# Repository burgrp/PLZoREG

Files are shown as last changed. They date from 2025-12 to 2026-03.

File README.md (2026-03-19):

# PLZoREG - PV Power Regulator

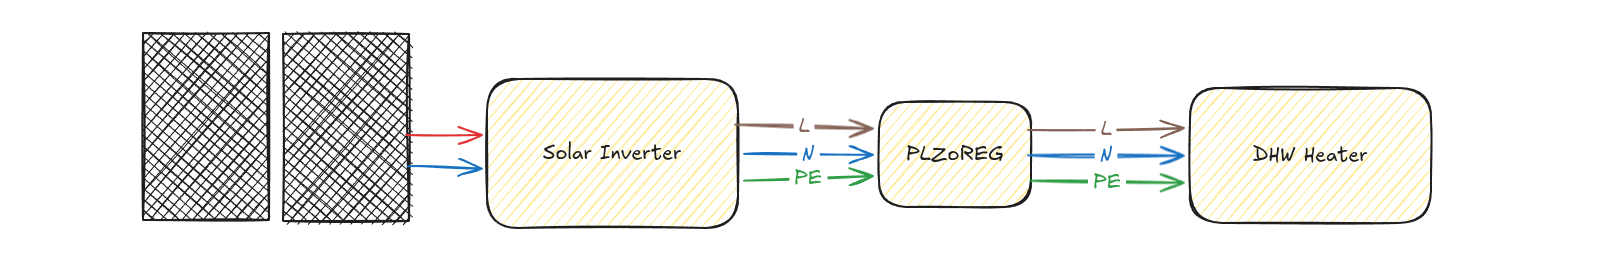
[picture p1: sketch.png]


PLZoREG is a power regulator designed to sit between a photovoltaic (PV) inverter and a domestic hot water (DHW) heater. It solves the problem of cheap grid-tie inverters oscillating under varying loads during cloudy conditions, which causes audible noise from the heating elements.

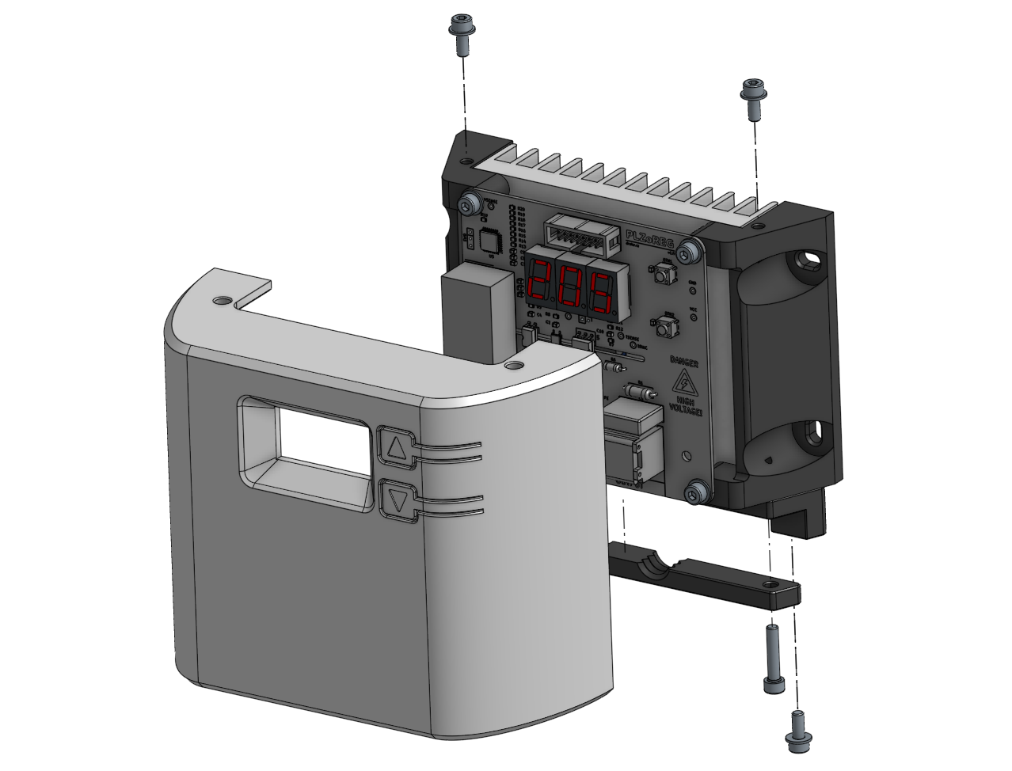
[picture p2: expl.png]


Designed in [Onshape](https://cad.onshape.com/documents/f103c5e3fbe2c6c85b2f1c34/w/b57b1089b11cbe9058b16474/e/0dcdb83c0b13157c67edb204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).

## Problem Statement

Low-cost PV inverters often struggle to maintain stable output when the load (DHW heater) exceeds the available solar power on cloudy days. The inverter attempts to deliver maximum power but fails to maintain output voltage, causing the load to cycle on and off rapidly. This creates:
- Audible buzzing/humming from heating spirals
- Inefficient operation and potential inverter shutdown
- Reduced energy harvesting

## Solution

PLZoREG monitors the inverter's output voltage and dynamically adjusts power delivery to the heater using phase-angle PWM control. By maintaining the inverter's output voltage above a configurable threshold, it prevents voltage collapse and keeps the inverter operating in its stable region.

### Key Features

- **Voltage monitoring**: Real-time measurement of inverter output voltage
- **Adaptive PWM regulation**: Automatic duty cycle adjustment (0-100%)
- **User-configurable target voltage**: Set target between 100-240V
- **Temperature monitoring**: Heater and MCU temperature sensing
- **Safety features**: Overtemperature protection, zero-cross synchronization detection
- **Persistent settings**: Target voltage stored in flash memory
- **Simple 2-button interface**: 3-digit 7-segment display with up/down controls

## Hardware

The hardware design is located in `board/` (KiCad 8 project).

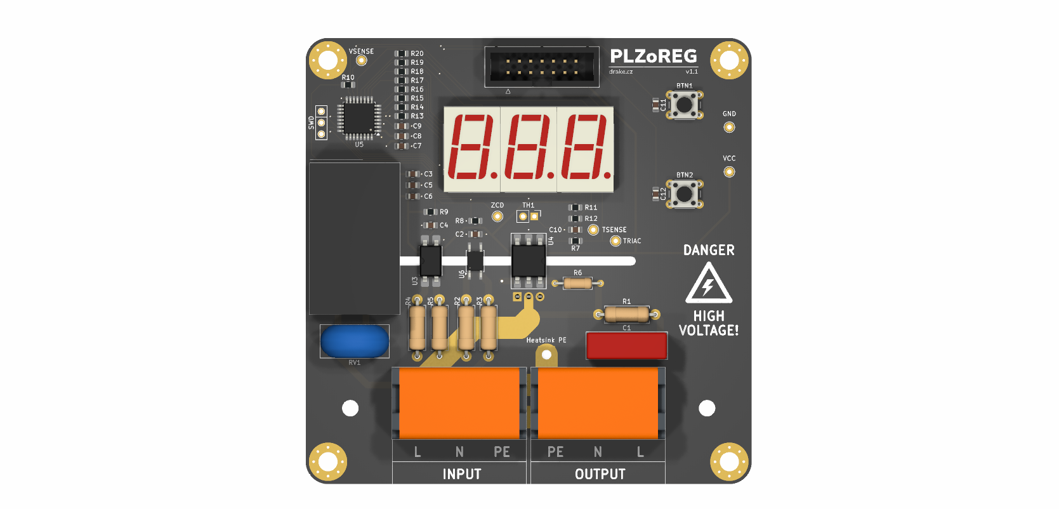
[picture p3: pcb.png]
PCB


**Microcontroller**: PY32F030x8 (ARM Cortex-M0+)

**Key Components**:
- Zero-cross detection for AC synchronization
- Phase-angle PWM control for power regulation
- Voltage sensing circuitry
- Temperature sensors (NTC for heater, internal for MCU)
- 3-digit 7-segment LED display
- 2-button user interface

## Firmware

The firmware is written in TinyGo and located in `fw/`.

### Prerequisites

- [TinyGo](https://tinygo.org/) (latest version recommended)
- [pyOCD](https://pyocd.io/) for flashing
- ARM GCC toolchain (for debugging)
- Make

### Building and Flashing

```bash
cd fw
make build    # Compile firmware
make flash    # Build and flash to device
```

### Debugging

```bash
make gdb      # Start GDB server with semihosting
make rtt      # Connect to RTT output for debug messages
```

### Architecture

**Key Packages**:
- `main.go`: Main control loop, state machine, regulation algorithm
- `display/`: 7-segment LED display driver (hardware-abstracted with build tags)
- `keyboard/`: Button input handler with key repeat and press detection
- `flash/`: Flash memory operations for persistent settings
- `adc/`, `pwm/`, `zcd/`: Hardware peripheral drivers

**Control Algorithm**:
The regulation loop (500ms cycle) compares sensed voltage with target voltage:
- If `VSense < VTarget`: Decrease duty cycle (reduce load)
- If `VSense > VTarget`: Increase duty cycle (increase load)
- Duty cycle changes by ±1% per cycle for smooth regulation

**Build Tags**: The project uses Go build tags for hardware abstraction:
- `py32`: PY32 family-specific code
- `py32f030`: PY32F030 variant-specific pin mappings

### User Interface

The firmware provides a page-based UI with 5 information pages:
1. **Voltage Sense** (no decimal): Current inverter voltage (e.g., `220`)
2. **Voltage Target** (trailing decimal): Target voltage setpoint - adjustable (e.g., `220.`)
3. **Duty Cycle** (decimal format): Current PWM duty cycle (e.g., `0.75` = 75%)
4. **Triac Temperature** (° symbol): Triac heatsink temperature (e.g., `50°`)
5. **MCU Temperature** (.° symbols): Microcontroller temperature (e.g., `50.°`)

Navigation:
- **Up/Down buttons**: Cycle through pages
- **Hold both buttons (1s)**: Enter/exit setting mode on adjustable pages (V. and .d)
- **In setting mode**: Up/Down buttons adjust the value

Error Codes:
- **E01**: No zero-cross synchronization detected
- **E02**: Overtemperature (triac > 90°C)

## Development

See [CLAUDE.md](CLAUDE.md) for detailed development guidance and architecture notes for AI assistants.

### Code Style

- Minimal abstractions: code is direct and hardware-focused
- No dynamic memory allocation (GC disabled)
- Task-based scheduler
- Prefer clarity over brevity

### Making Changes

1. Ensure all builds run from `fw/` directory
2. Test display changes across build tag variants
3. Verify settings persistence after power cycle
4. Check regulation stability under varying voltage conditions

## License

[Add license information]

## Contributing

[Add contribution guidelines if applicable]

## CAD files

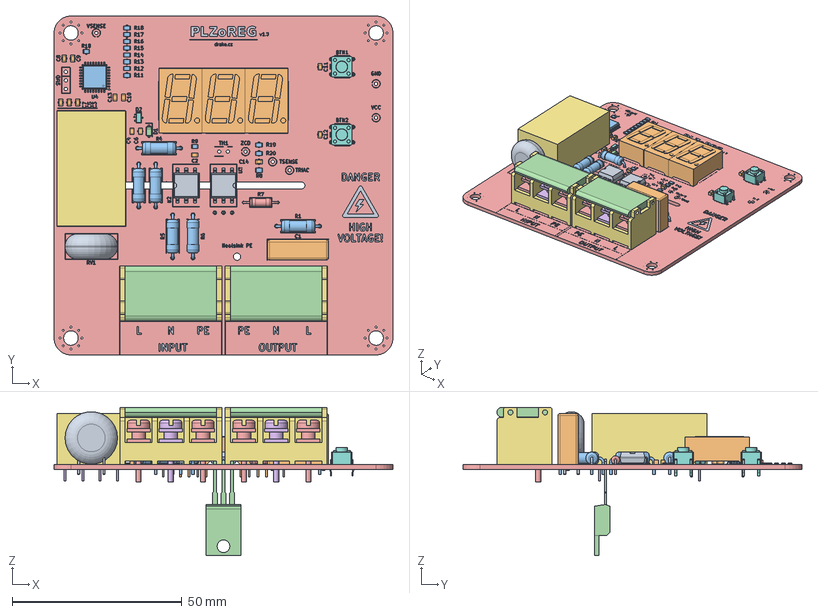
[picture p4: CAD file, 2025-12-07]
board/plzoreg.step
100.0 x 100.0 x 43.8 mm
C_0805_2012Metric x 13
R_0805_2012Metric x 13
cover x 2
contact 1 x 2
SOT-23
RV_Disc_D15.5mm_W7.5mm_P7.5mm
7SegmentLED_LTS6760_LTS6780 x 3
R_Axial_DIN0411_L9.9mm_D3.6mm_P12.70mm_Horizontal x 6
D_SOD-123
R_Axial_DIN0207_L6.3mm_D2.5mm_P10.16mm_Horizontal
HLK-PM01-ac2
HLK-PM01-vo-
HLK-PM01-vo+
HLK-PM01-ac1
HLK-PM01-body
SW_PUSH_6mm_H5mm x 2
DIP-6_W8.89mm_SMDSocket x 2
C_Rect_L18.0mm_W6.0mm_P15.00mm_FKS3_FKP3
LQFP-32_7x7mm_P0.8mm
TO-220-3_Vertical
plzoreg_silkscreen x 2
plzoreg_PCB

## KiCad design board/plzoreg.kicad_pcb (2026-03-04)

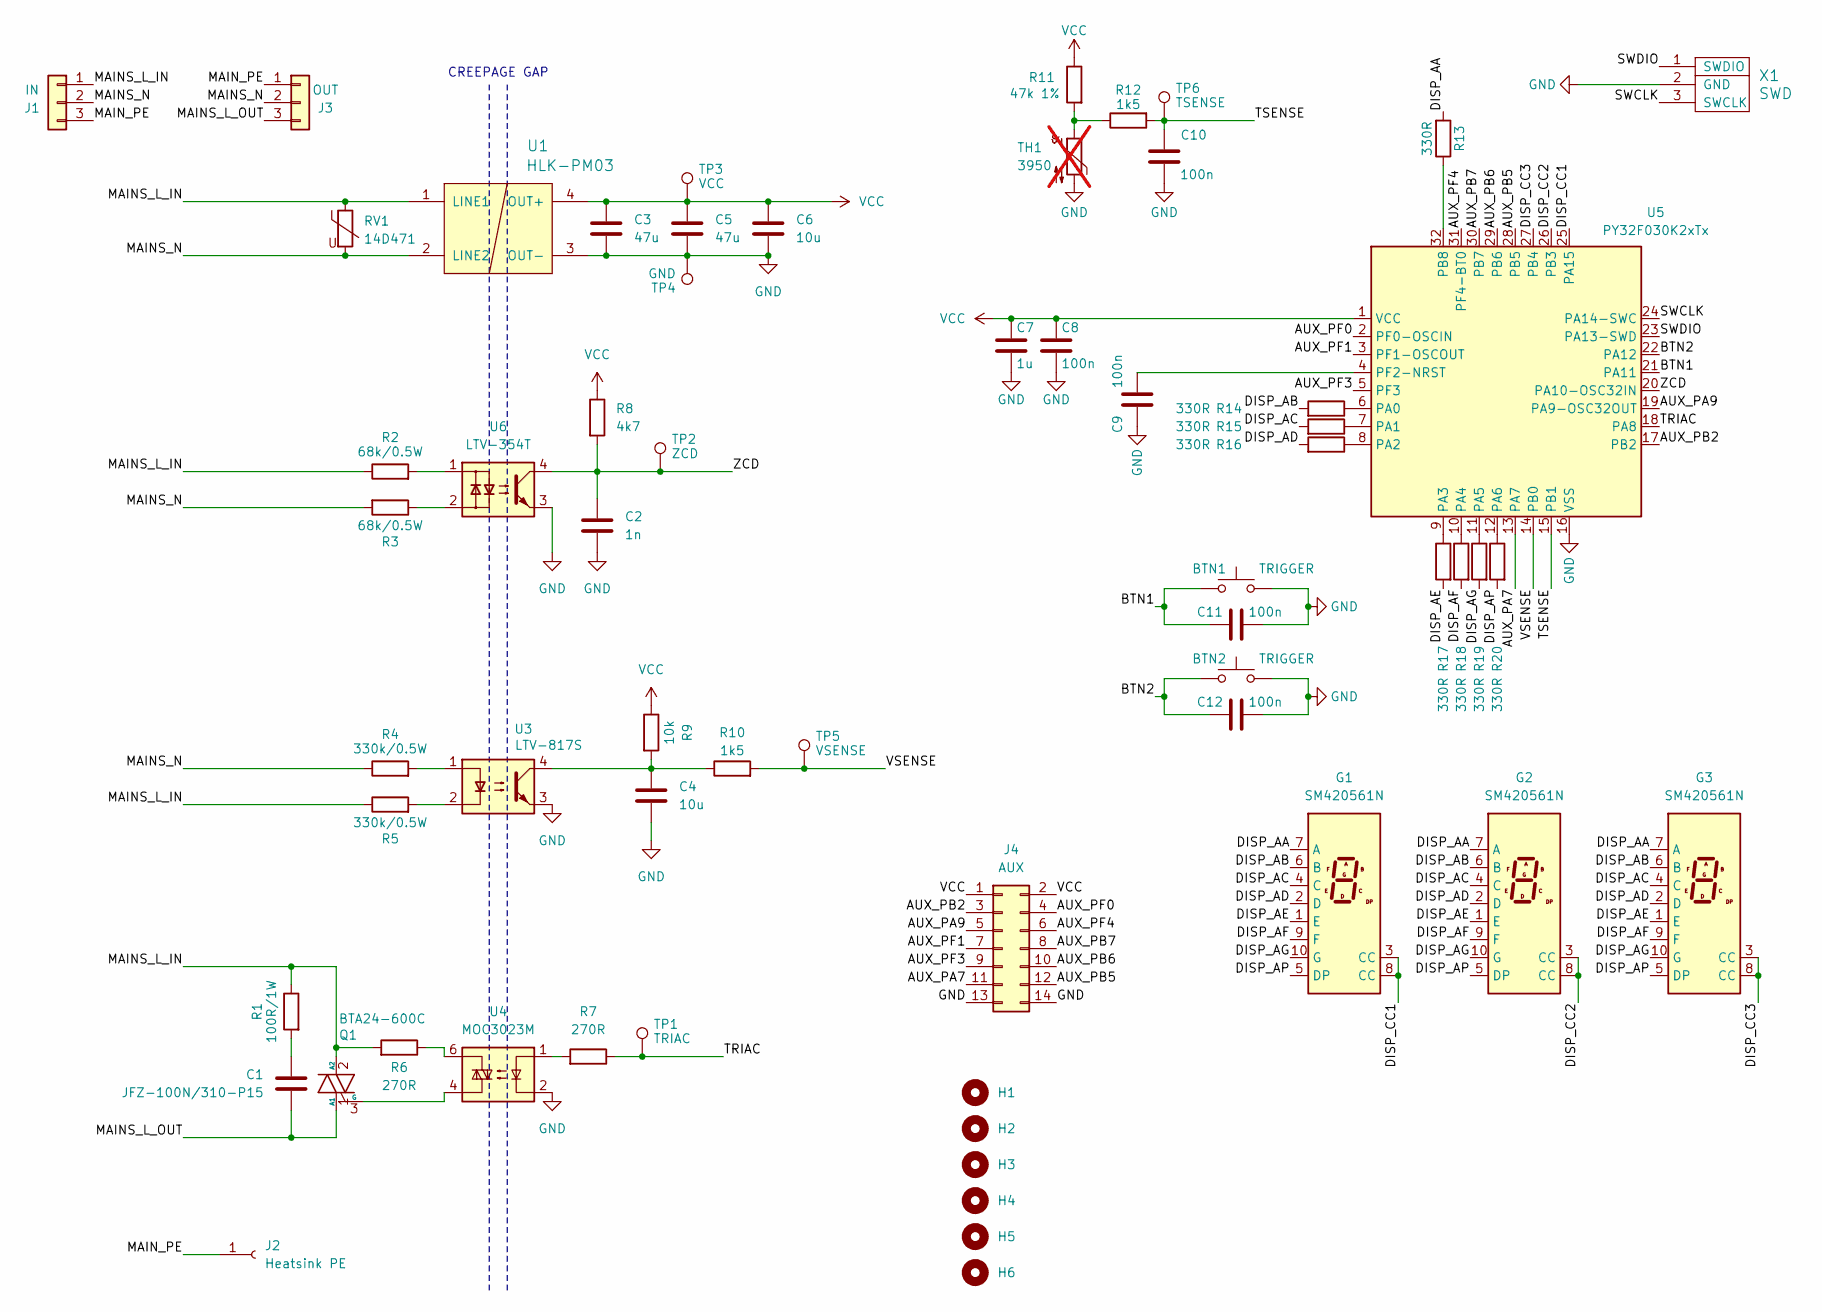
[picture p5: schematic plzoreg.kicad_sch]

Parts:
BTN1, BTN2: TRIGGER; SW_PUSH_6mm_H5mm
C1: JFZ-100N/310-P15; C_Rect_L18.0mm_W6.0mm_P15.00mm_FKS3_FKP3
C2: 1n; C_0805_2012Metric_Pad1.18x1.45mm_HandSolder
C3, C5: 47u; C_0805_2012Metric_Pad1.18x1.45mm_HandSolder
C4, C6: 10u; C_0805_2012Metric_Pad1.18x1.45mm_HandSolder
C7: 1u; C_0805_2012Metric_Pad1.18x1.45mm_HandSolder
C8, C9, C10, C11, C12: 100n; C_0805_2012Metric_Pad1.18x1.45mm_HandSolder
G1, G2, G3: SM420561N; 7SegmentLED_LTS6760_LTS6780
H1, H2, H3, H4: MountingHole; MountingHole_4.3mm_M4_Pad_Via
H5, H6: MountingHole; MountingHole_3.7mm
J1: IN; HB-9500-3P
J2: Heatsink PE; SolderWire-1.5sqmm_1x01_D1.7mm_OD3.9mm
J3: OUT; HB-9500-3P
J4: AUX; IDC-Header_2x07_P2.54mm_Vertical
Q1: BTA24-600C; TO-220-3_Vertical
R1: 100R/1W; R_Axial_DIN0411_L9.9mm_D3.6mm_P12.70mm_Horizontal
R2, R3: 68k/0.5W; R_Axial_DIN0411_L9.9mm_D3.6mm_P12.70mm_Horizontal
R4, R5: 330k/0.5W; R_Axial_DIN0411_L9.9mm_D3.6mm_P12.70mm_Horizontal
R6: 270R; R_Axial_DIN0207_L6.3mm_D2.5mm_P10.16mm_Horizontal
R7: 270R; R_0805_2012Metric_Pad1.20x1.40mm_HandSolder
R8: 4k7; R_0805_2012Metric_Pad1.20x1.40mm_HandSolder
R9: 10k; R_0805_2012Metric_Pad1.20x1.40mm_HandSolder
R10, R12: 1k5; R_0805_2012Metric_Pad1.20x1.40mm_HandSolder
R11: 47k 1%; R_0805_2012Metric_Pad1.20x1.40mm_HandSolder
R13, R14, R15, R16, R17, R18, R19, R20: 330R; R_0805_2012Metric_Pad1.20x1.40mm_HandSolder
RV1: 14D471; RV_Disc_D15.5mm_W7.5mm_P7.5mm
TH1: 3950; PinHeader_1x02_P2.54mm_Vertical; not fitted
TP1: TRIAC; TestPoint_THTPad_D2.0mm_Drill1.0mm
TP2: ZCD; TestPoint_THTPad_D2.0mm_Drill1.0mm
TP3: VCC; TestPoint_THTPad_D2.0mm_Drill1.0mm
TP4: GND; TestPoint_THTPad_D2.0mm_Drill1.0mm
TP5: VSENSE; TestPoint_THTPad_D2.0mm_Drill1.0mm
TP6: TSENSE; TestPoint_THTPad_D2.0mm_Drill1.0mm
U1: HLK-PM03; HLK-PM01
U3: LTV-817S; SMDIP-4_W9.53mm
U4: MOC3023M; DIP-6_W8.89mm_SMDSocket_LongPads
U5: PY32F030K2xTx; LQFP-32_7x7mm_P0.8mm
U6: LTV-354T; SO-4_4.4x3.6mm_P2.54mm
X1: SWD

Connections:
/AUX_PA7: J4.11, U5.13 (PA7)
/AUX_PA9: J4.5, U5.19 (PA9-OSC32OUT)
/AUX_PB2: J4.3, U5.17 (PB2)
/AUX_PB5: J4.12, U5.28 (PB5)
/AUX_PB6: J4.10, U5.29 (PB6)
/AUX_PB7: J4.8, U5.30 (PB7)
/AUX_PF0: J4.4, U5.2 (PF0-OSCIN)
/AUX_PF1: J4.7, U5.3 (PF1-OSCOUT)
/AUX_PF3: J4.9, U5.5 (PF3)
/AUX_PF4: J4.6, U5.31 (PF4-BT0)
/BTN1: BTN1.1, C11.1, U5.21 (PA11)
/BTN2: BTN2.1, C12.1, U5.22 (PA12)
/DISP_AA: G1.7 (A), G2.7 (A), G3.7 (A), R13.2
/DISP_AB: G1.6 (B), G2.6 (B), G3.6 (B), R14.2
/DISP_AC: G1.4 (C), G2.4 (C), G3.4 (C), R15.2
/DISP_AD: G1.2 (D), G2.2 (D), G3.2 (D), R16.2
/DISP_AE: G1.1 (E), G2.1 (E), G3.1 (E), R17.2
/DISP_AF: G1.9 (F), G2.9 (F), G3.9 (F), R18.2
/DISP_AG: G1.10 (G), G2.10 (G), G3.10 (G), R19.2
/DISP_AP: G1.5 (DP), G2.5 (DP), G3.5 (DP), R20.2
/DISP_CC1: G1.3 (CC), G1.8 (CC), U5.25 (PA15)
/DISP_CC2: G2.3 (CC), G2.8 (CC), U5.26 (PB3)
/DISP_CC3: G3.3 (CC), G3.8 (CC), U5.27 (PB4)
/MAINS_L_IN: J1.1, Q1.2 (A2), R1.1, R2.1, R5.1, R6.2, RV1.1, U1.1 (LINE1)
/MAINS_L_OUT: C1.2, J3.3, Q1.1 (A1)
/MAINS_N: J1.2, J3.2, R3.2, R4.1, RV1.2, U1.2 (LINE2)
/MAIN_PE: J1.3, J2.1, J3.1
/SWCLK: U5.24 (PA14-SWC), X1.3 (SWCLK)
/SWDIO: U5.23 (PA13-SWD), X1.1 (SWDIO)
/TRIAC: R7.1, TP1.1, U5.18 (PA8)
/TSENSE: C10.2, R12.2, TP6.1, U5.15 (PB1)
/VSENSE: R10.2, TP5.1, U5.14 (PB0)
/ZCD: C2.1, R8.2, TP2.1, U5.20 (PA10-OSC32IN), U6.4
GND: BTN1.2, BTN2.2, C2.2, C3.2, C4.2, C5.2, C6.2, C7.2, C8.2, C9.2, C10.1, C11.2, C12.2, J4.13, J4.14, TH1.2, TP4.1, U1.3 (OUT-), U3.3, U4.2, U5.16 (VSS), U6.3, X1.2 (GND)
unnamed: C1.1, R1.2
unnamed: C4.1, R9.2, R10.1, U3.4
unnamed: Q1.3 (G), U4.4
unnamed: R2.2, U6.1
unnamed: R3.1, U6.2
unnamed: R4.2, U3.1
unnamed: R5.2, U3.2
unnamed: R6.1, U4.6
unnamed: R7.2, U4.1
unnamed: R11.2, R12.1, TH1.1
unnamed: R14.1, U5.6 (PA0)
unnamed: R15.1, U5.7 (PA1)
unnamed: R16.1, U5.8 (PA2)
unnamed: R17.1, U5.9 (PA3)
unnamed: R18.1, U5.10 (PA4)
unnamed: R19.1, U5.11 (PA5)
unnamed: R20.1, U5.12 (PA6)
unnamed: R13.1, U5.32 (PB8)
unnamed: C9.1, U5.4 (PF2-NRST)
VCC: C3.1, C5.1, C6.1, C7.1, C8.1, J4.1, J4.2, R8.1, R9.1, R11.1, TP3.1, U1.4 (OUT+), U5.1 (VCC)

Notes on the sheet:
CREEPAGE GAP

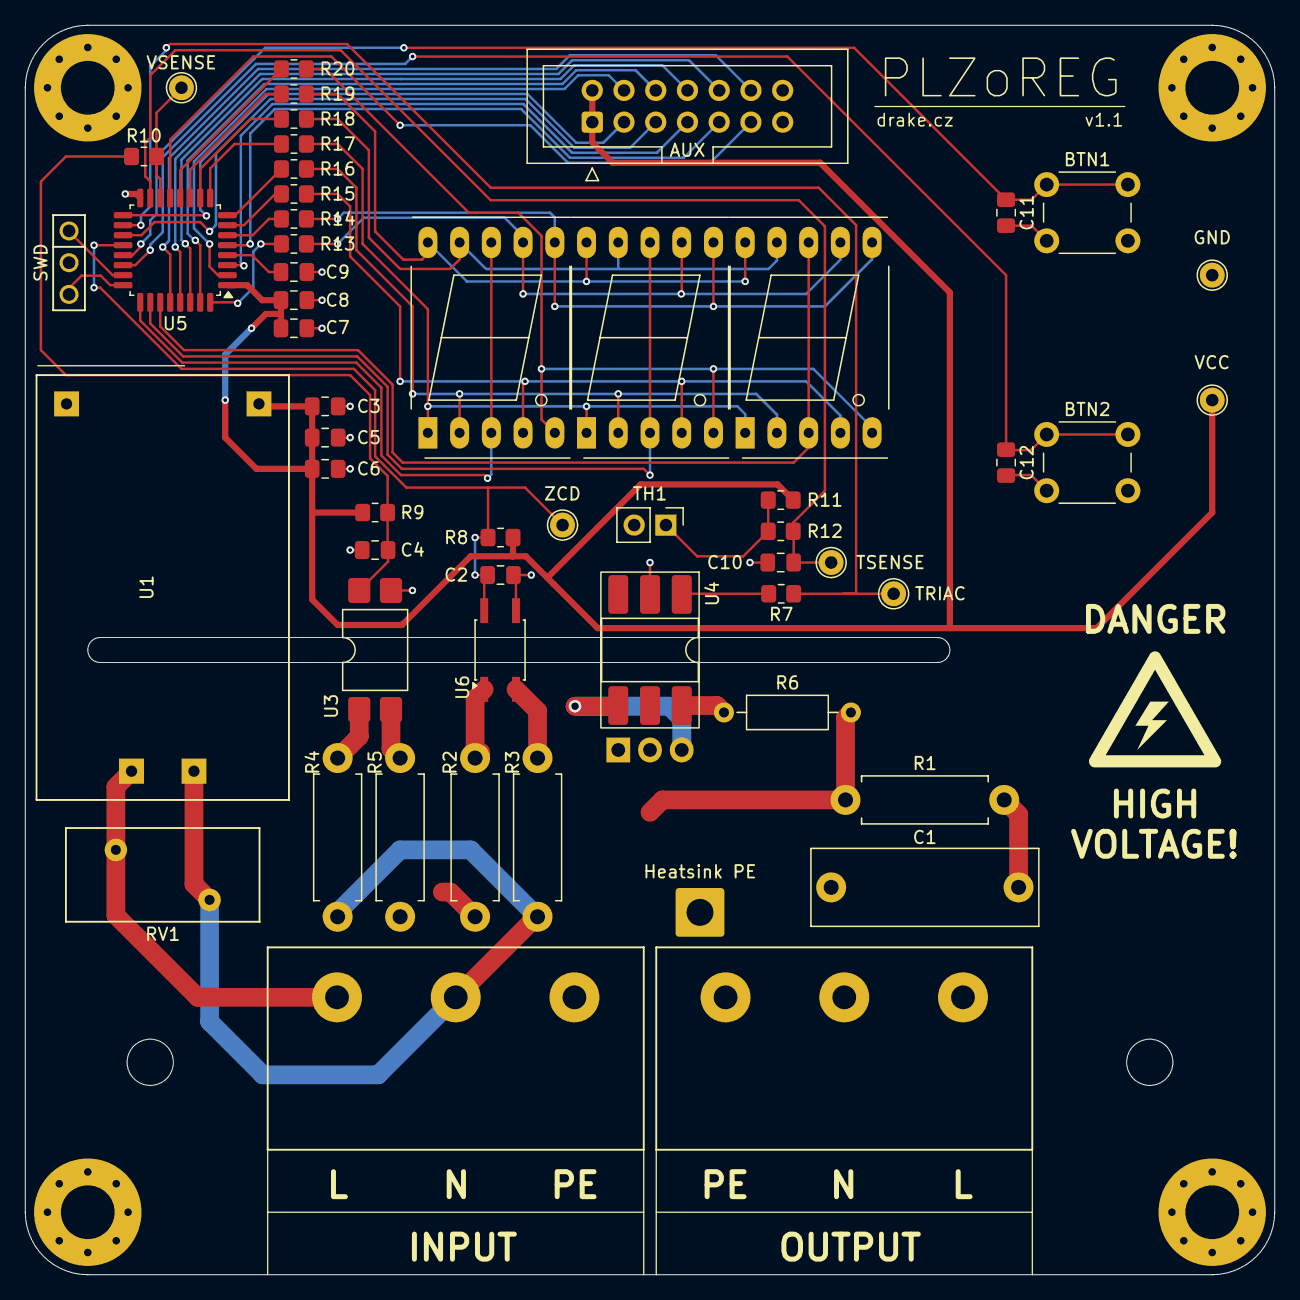
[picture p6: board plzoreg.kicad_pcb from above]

Board: 2 copper layers, 100.0 x 100.0 mm, 62 parts (1 on the bottom side), 54 nets.

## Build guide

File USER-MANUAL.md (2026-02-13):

# PLZoREG User Manual

## Introduction

PLZoREG is an automatic power regulator that sits between your photovoltaic (PV) inverter and electric water heater. It prevents your inverter from shutting down or making noise during cloudy weather by smoothly controlling the power delivered to your heater.

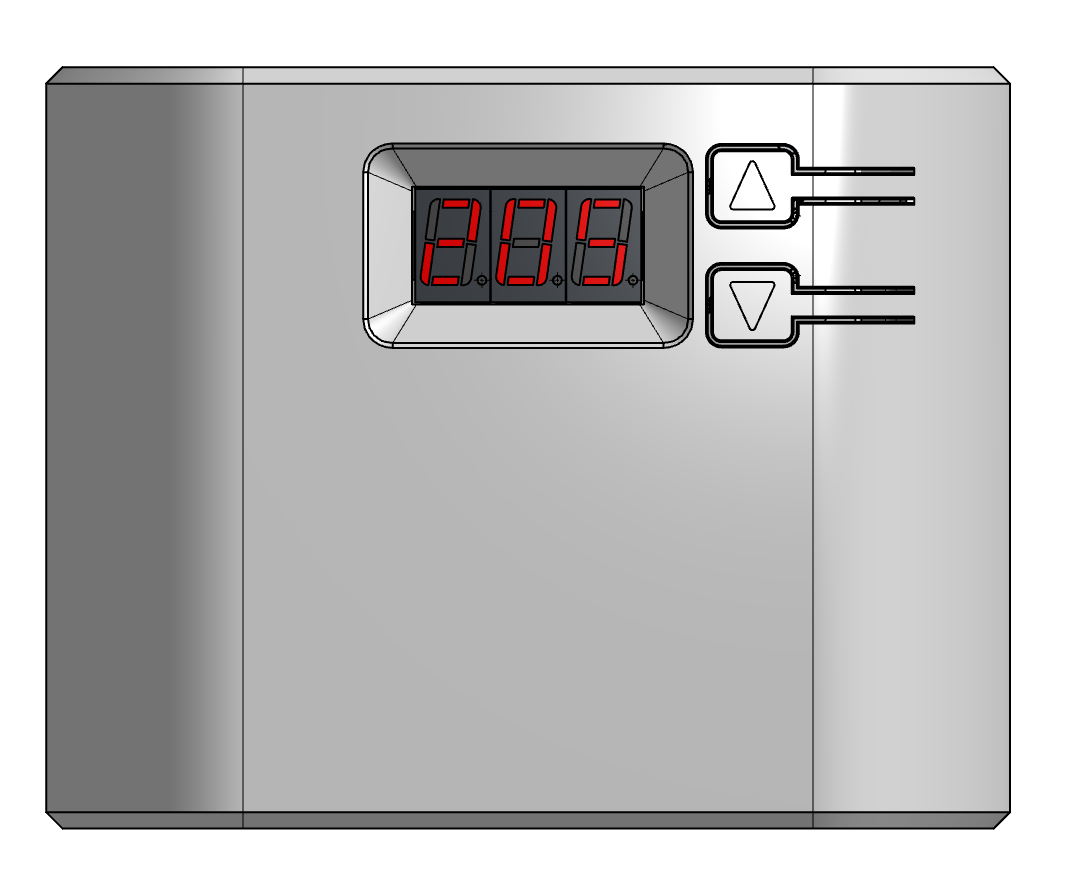
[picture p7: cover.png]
PLZoREG


## Installation

**WARNING**: Installation involves high voltage AC wiring. Installation must be performed by a qualified electrician in accordance with local electrical codes.

1. Mount the device in a suitable location between the inverter and heater
2. Connect the input to your PV inverter's AC output
3. Connect the output to your water heater
4. Ensure proper grounding and circuit protection
5. Power on the system

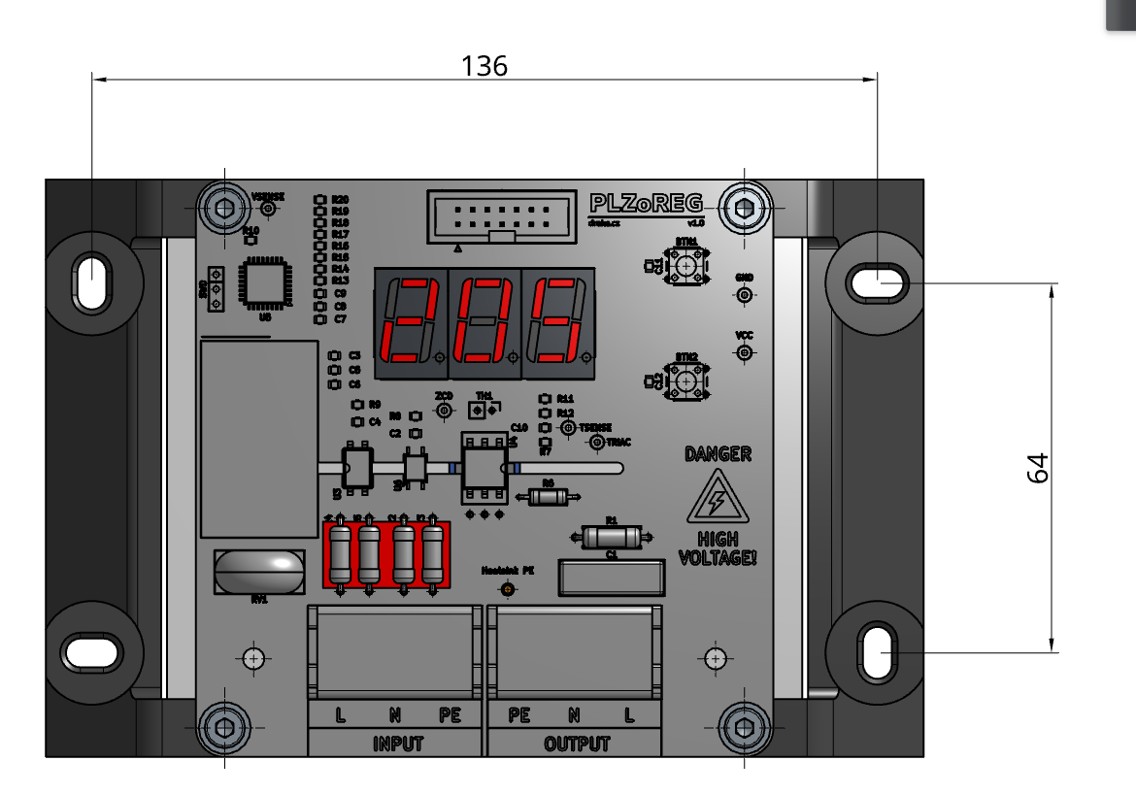
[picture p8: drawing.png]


## Display and Controls

The device has a **3-digit display** and **two buttons**:
- **UP button** (↑)
- **DOWN button** (↓)

The display shows different information depending on which page is selected.

## Operating Pages

Press the UP or DOWN button to cycle through the information pages:

### 1. Voltage Sense
**Display**: Voltage without decimal point (e.g., `220`)

Shows the current voltage from your PV inverter. This value changes as cloud cover varies.

- **Normal operation**: 180-240V (depends on your system)
- **Action**: None required - informational only

### 2. Voltage Target
**Display**: Voltage followed by decimal point (e.g., `220.`)

This is the **target voltage** you want to maintain. The device will reduce power to the heater if the inverter voltage drops below this value.

**To adjust**:
1. Hold BOTH buttons for 1 second - the decimal point will blink
2. Press UP to increase, DOWN to decrease (range: 100-240V)
3. Hold BOTH buttons for 1 second to save and exit

**Recommended setting**: 200-210V for most systems
- **Higher values** (220-230V): More conservative, less noise, but less power usage
- **Lower values** (180-200V): More aggressive, uses more solar power, but may cause occasional inverter instability

### 3. Duty Cycle
**Display**: Duty cycle as decimal number (e.g., `0.75` = 75%)

Shows the current power level being delivered to the heater:
- **0.00**: No power (heater off)
- **1.00**: Full power (heater at maximum)

The device automatically adjusts this value to maintain your target voltage.

**Manual override** (advanced):
1. Hold BOTH buttons for 1 second to enter manual mode
2. Press UP/DOWN to adjust in 5% increments
3. Hold BOTH buttons to exit manual mode (automatic regulation resumes)

### 4. Triac Heatsink Temperature
**Display**: `°` Temperature followed by ° symbol (e.g., `50°`)

Shows the temperature of the switching element (informational value):
- **Normal**: 20-80°C during operation
- **Warning**: Above 90°C triggers safety shutdown

### 5. MCU Temperature
**Display**: `.°` Temperature followed by decimal point and ° symbol (e.g., `50.°`)

Shows the device's internal temperature (informational value):
- **Normal**: 20-60°C
- **Informational only** - no action required

## Error Codes

If an error occurs, the display shows `E` followed by a number:

### E01 - No Synchronization
**Meaning**: Device cannot detect AC power synchronization signal

**Possible causes**:
- No input power
- Wiring issue
- Hardware fault

**Action**: Check that the inverter is powered and outputting AC. If problem persists, contact support.

### E02 - Overtemperature
**Meaning**: Triac temperature exceeded 90°C

**Possible causes**:
- Insufficient cooling/ventilation
- Excessive load current
- Hardware fault

**Action**:
1. Immediately disconnect power
2. Check device ventilation and cooling
3. Verify load current is within specifications
4. Allow system to cool before restarting

**Safety note**: When any error is active, power output is automatically shut off.

## Normal Operation

1. **Sunny conditions**:
   - Display shows V.sense near or above V.target
   - Duty cycle approaches 100%
   - Maximum power delivered to heater

2. **Partly cloudy**:
   - Display shows V.sense fluctuating
   - Duty cycle adjusts automatically (20-90%)
   - Device regulates power smoothly

3. **Very cloudy/low light**:
   - Display shows V.sense at or below V.target
   - Duty cycle near 0%
   - Minimal power to heater

## Tips for Optimal Operation

- **Set target voltage conservatively** on first use - start at 210V and adjust down if system is stable
- **Monitor for a few days** under various weather conditions before making final adjustments
- **Check temperature page** occasionally to ensure heater is operating normally
- **Don't set target too low** - this defeats the purpose and may cause the noise you're trying to avoid

## Maintenance

- No regular maintenance required
- Keep ventilation openings clear
- Periodically check that display is functioning
- Verify temperature readings are reasonable

## Specifications

- **Input voltage**: 100-240V AC (from PV inverter)
- **Output control**: 0-100% phase-angle PWM
- **Target voltage range**: 100-240V (user configurable)
- **Temperature monitoring**: Up to 90°C (safety limit)
- **Response time**: 500ms update cycle
- **Settings retention**: Non-volatile (survives power loss)

## Troubleshooting

| Symptom | Possible Cause | Solution |
|---|---|---|
| Display blank | No power | Check input power |
| Constant E01 error | No AC input | Verify inverter is active |
| E02 error frequently | Overheating | Check ventilation and cooling |
| Inverter still noisy | Target voltage too low | Increase target voltage setting |
| Low power usage | Target voltage too high | Decrease target voltage setting |
| Display showing wrong values | Needs recalibration | Contact support |

## Technical Support

[Add contact information]

## Safety Warnings

- ⚠️ **HIGH VOLTAGE** - Do not open the device enclosure
- ⚠️ **Installation by qualified personnel only**
- ⚠️ **Do not bypass error conditions**
- ⚠️ **Ensure proper grounding**

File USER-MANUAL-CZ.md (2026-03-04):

# PLZoREG Uživatelská Příručka

## Úvod

PLZoREG je automatický regulátor výkonu, který se instaluje mezi fotovoltaický (FV) střídač a elektrický ohřívač vody. Zabraňuje vypínání střídače nebo vzniku hluku během proměnlivého počasí tím, že plynule řídí výkon dodávaný do ohřívače.

PLZoREG

## Instalace

**VAROVÁNÍ**: Instalace zahrnuje práci s vysokým napětím. Instalaci musí provést kvalifikovaný elektrikář v souladu s místními elektrotechnickými předpisy.

1. Namontujte zařízení na vhodné místo mezi střídač a ohřívač
2. Připojte vstup k AC výstupu vašeho FV střídače
3. Připojte výstup k vašemu ohřívači vody
4. Zajistěte správné uzemnění a ochranu obvodu
5. Zapněte systém



## Displej a Ovládání

Zařízení má **3-místný displej** a **dvě tlačítka**:
- **Tlačítko NAHORU** (↑)
- **Tlačítko DOLŮ** (↓)

Displej zobrazuje různé informace v závislosti na vybrané stránce.

## Provozní Stránky

Stisknutím tlačítka NAHORU nebo DOLŮ procházejte jednotlivé informační stránky:

### 1. Měřené Napětí
**Displej**: napětí bez desetinné tečky (např. `220`)

Zobrazuje aktuální napětí z vašeho FV střídače. Tato hodnota se mění podle oblačnosti.

- **Normální provoz**: 180-240V (závisí na vašem systému)
- **Akce**: Není vyžadována - pouze informativní

### 2. Cílové Napětí
**Displej**: napětí následované desetinnou tečkou (např. `220.`)

Toto je **cílové napětí**, které chcete udržovat. Zařízení sníží výkon do ohřívače, pokud napětí střídače klesne pod tuto hodnotu.

**Nastavení**:
1. Podržte OBĚ tlačítka po dobu 1 sekundy - desetinná tečka začne blikat
2. Stiskněte NAHORU pro zvýšení, DOLŮ pro snížení (rozsah: 100-240V)
3. Podržte OBĚ tlačítka po dobu 1 sekundy pro uložení a ukončení

**Doporučené nastavení**: 200-210V pro většinu systémů
- **Vyšší hodnoty** (220-230V): Konzervativnější, méně hluku, ale menší využití energie
- **Nižší hodnoty** (180-200V): Agresivnější, využívá více solární energie, ale může občas způsobit nestabilitu střídače

### 3. Pracovní Cyklus
**Displej**: Pracovní cyklus jako desetinné číslo (např. `0.75` = 75%)

Zobrazuje aktuální úroveň výkonu dodávaného do ohřívače:
- **0.00**: Žádný výkon (ohřívač vypnutý)
- **1.00**: Plný výkon (ohřívač na maximum)

Zařízení automaticky upravuje tuto hodnotu pro udržení cílového napětí.

**Ruční režim** (pokročilé):
1. Podržte OBĚ tlačítka po dobu 1 sekundy pro vstup do ručního režimu
2. Stiskněte NAHORU/DOLŮ pro úpravu po 5% krocích
3. Podržte OBĚ tlačítka pro ukončení ručního režimu (automatická regulace pokračuje)

### 4. Teplota chladiče triaku
**Displej**: `°` teplota následovaná symbolem ° (např. `50°`)

Zobrazuje teplotu spínacího prvku (informační hodnota):
- **Normální**: 20-80°C během provozu
- **Varování**: Nad 90°C spustí bezpečnostní vypnutí

### 5. Teplota MCU
**Displej**: `.°` teplota následovaná desetinnou tečkou a symbolem ° (např. `50.°`)

Zobrazuje vnitřní teplotu zařízení (informační hodnota):
- **Normální**: 20-60°C
- **Pouze informativní** - není vyžadována akce

## Chybové Kódy

Pokud dojde k chybě, displej zobrazí `E` následované číslem:

### E01 - Chybí Synchronizace
**Význam**: Zařízení nemůže detekovat synchronizační signál AC napájení

**Možné příčiny**:
- Chybí vstupní napájení
- Problém s kabeláží
- Hardwarová závada

**Řešení**: Zkontrolujte, že střídač je zapnutý a vydává AC napětí. Pokud problém přetrvává, kontaktujte podporu.

### E02 - Přehřátí
**Význam**: Teplota triaku překročila 90°C

**Možné příčiny**:
- Nedostatečné chlazení/větrání
- Nadměrný proud zátěže
- Hardwarová závada

**Řešení**:
1. Okamžitě odpojte napájení
2. Zkontrolujte větrání a chlazení zařízení
3. Ověřte, že proud zátěže je v rámci specifikací
4. Před restartováním nechte systém vychladnout

**Bezpečnostní upozornění**: Když je aktivní jakákoli chyba, výstup výkonu je automaticky vypnutý.

## Normální Provoz

1. **Slunečné podmínky**:
   - Displej zobrazuje V.sense blízko nebo nad V.target
   - Pracovní cyklus se blíží 100%
   - Maximální výkon dodávaný do ohřívače

2. **Částečně zataženo**:
   - Displej zobrazuje kolísající V.sense
   - Pracovní cyklus se automaticky upravuje (20-90%)
   - Zařízení reguluje výkon plynule

3. **Velmi zataženo/málo světla**:
   - Displej zobrazuje V.sense na nebo pod V.target
   - Pracovní cyklus blízko 0%
   - Minimální výkon do ohřívače

## Tipy pro Optimální Provoz

- **Nastavte cílové napětí konzervativně** při prvním použití - začněte na 210V a snižujte, pokud je systém stabilní
- **Sledujte několik dní** za různých povětrnostních podmínek před finálním nastavením
- **Pravidelně kontrolujte teplotní stránku**, abyste se ujistili, že ohřívač funguje normálně
- **Nenastavujte cíl příliš nízko** - tím ztrácíte smysl a můžete způsobit hluk, kterému se snažíte vyhnout

## Údržba

- Není vyžadována pravidelná údržba
- Udržujte ventilační otvory čisté
- Pravidelně kontrolujte, že displej funguje
- Ověřte, že teplotní údaje jsou rozumné

## Specifikace

- **Vstupní napětí**: 100-240V AC (z FV střídače)
- **Výstupní řízení**: 0-100% fázové PWM
- **Rozsah cílového napětí**: 100-240V (uživatelsky nastavitelné)
- **Sledování teploty**: Až do 90°C (bezpečnostní limit)
- **Reakční čas**: 500ms aktualizační cyklus
- **Uchování nastavení**: Nevolatilní (přežije ztrátu napájení)

## Řešení Problémů

| Příznak | Možná Příčina | Řešení |
|---|---|---|
| Displej nesvítí | Chybí napájení | Zkontrolujte vstupní napájení |
| Trvalá chyba E01 | Chybí AC vstup | Ověřte, že střídač je aktivní |
| Častá chyba E02 | Přehřátí | Zkontrolujte větrání a chlazení |
| Střídač stále hlučí | Cílové napětí příliš nízké | Zvyšte nastavení cílového napětí |
| Nízké využití energie | Cílové napětí příliš vysoké | Snižte nastavení cílového napětí |
| Displej zobrazuje špatné hodnoty | Vyžaduje kalibraci | Kontaktujte podporu |

## Technická Podpora

[Doplňte kontaktní informace]

## Bezpečnostní Varování

- ⚠️ **VYSOKÉ NAPĚTÍ** - Neotvírejte kryt zařízení
- ⚠️ **Instalace pouze kvalifikovaným personálem**
- ⚠️ **Nepřemosťujte chybové stavy**
- ⚠️ **Zajistěte správné uzemnění**

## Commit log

2026-02-01 Refactor pin definitions: move pinKeyUp and pinKeyDown constants to a dedicated block and update keyboard initialization
2026-02-13 Update PWM settings to handle inactive state by setting CCR1 and ARR to maximum values
2026-03-04 Update user manual to clarify internal temperature display and error handling instructions
2026-03-04 v1.1: fixed triac gate issue
    [plzoreg.kicad_pcb, plzoreg.kicad_sch]
2026-03-19 Add PCB image to README and update design section
